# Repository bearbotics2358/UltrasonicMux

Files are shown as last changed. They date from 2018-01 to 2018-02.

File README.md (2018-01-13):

# UltrasonicMux
  This program reads up to 4 Maxbotix ultrasonic sensors and sends
  the output back to the connected computer (CRIO).
  
  The program triggers one sensor at a time and reads its response.
  It waits up to 100 msec for the response.  If none is recevied, it
  substitutes a reading of "999".
  
  A Maxbotix sensor output string example is "R123<CR>".  The program
  substitutes "A", "B", "C", or "D" for the "R", depending on which
  sensor.
  
  The CR is replaced with a TAB for all but the last enabled sensor
  to assist in debugging.
  
  The src/mux subdirectory has the Arduino code for the Ultrasonic Multiplexer.
  
  The src/robot subdirectory has the Sonar class for the robot.

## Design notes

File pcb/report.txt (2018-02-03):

Info: Reading netlist file "V:\Robotics Club\FIRST\Software\17-18 Season\Ultrasonic Mux\pcb\Ultrasonic_mux.net".

Info: Using references to match components and footprints.

Info: Checking netlist component footprint "+3V3p1:/5A757808:Pin_Headers:Pin_Header_Angled_1x01_Pitch2.54mm".

Adding new component "+3V3p1:/5A757808" footprint "Pin_Headers:Pin_Header_Angled_1x01_Pitch2.54mm".

Changing component "+3V3p1:/5A757808" pin "1" net name from "" to "+3V3".

Info: Checking netlist component footprint "+5Vp1:/5A757367:Pin_Headers:Pin_Header_Angled_1x01_Pitch2.54mm".

Adding new component "+5Vp1:/5A757367" footprint "Pin_Headers:Pin_Header_Angled_1x01_Pitch2.54mm".

Changing component "+5Vp1:/5A757367" pin "1" net name from "" to "+5V".

Info: Checking netlist component footprint "D0:/5A6FC6E7:Diodes_SMD:D_SOT-23_ANK".

Adding new component "D0:/5A6FC6E7" footprint "Diodes_SMD:D_SOT-23_ANK".

Changing component "D0:/5A6FC6E7" pin "2" net name from "" to "GNDPWR".

Changing component "D0:/5A6FC6E7" pin "1" net name from "" to "Net-(D0-Pad1)".

Info: Checking netlist component footprint "D1:/5A6FC6FF:LEDs:LED_0805_HandSoldering".

Adding new component "D1:/5A6FC6FF" footprint "LEDs:LED_0805_HandSoldering".

Changing component "D1:/5A6FC6FF" pin "1" net name from "" to "Net-(D1-Pad1)".

Changing component "D1:/5A6FC6FF" pin "2" net name from "" to "+3V3".

Info: Checking netlist component footprint "D2:/5A742F70:LEDs:LED_0603_HandSoldering".

Adding new component "D2:/5A742F70" footprint "LEDs:LED_0603_HandSoldering".

Changing component "D2:/5A742F70" pin "1" net name from "" to "Net-(D2-Pad1)".

Changing component "D2:/5A742F70" pin "2" net name from "" to "+3V3".

Info: Checking netlist component footprint "D10:/5A6FD7F3:Diodes_SMD:D_SOT-23_ANK".

Adding new component "D10:/5A6FD7F3" footprint "Diodes_SMD:D_SOT-23_ANK".

Changing component "D10:/5A6FD7F3" pin "2" net name from "" to "GNDPWR".

Changing component "D10:/5A6FD7F3" pin "1" net name from "" to "Net-(D10-Pad1)".

Info: Checking netlist component footprint "D11:/5A6FD80B:LEDs:LED_0805_HandSoldering".

Adding new component "D11:/5A6FD80B" footprint "LEDs:LED_0805_HandSoldering".

Changing component "D11:/5A6FD80B" pin "1" net name from "" to "Net-(D11-Pad1)".

Changing component "D11:/5A6FD80B" pin "2" net name from "" to "+3V3".

Info: Checking netlist component footprint "D12:/5A73E3A2:LEDs:LED_0603_HandSoldering".

Adding new component "D12:/5A73E3A2" footprint "LEDs:LED_0603_HandSoldering".

Changing component "D12:/5A73E3A2" pin "1" net name from "" to "Net-(D12-Pad1)".

Changing component "D12:/5A73E3A2" pin "2" net name from "" to "+3V3".

Info: Checking netlist component footprint "D20:/5A6FDC3E:Diodes_SMD:D_SOT-23_ANK".

Adding new component "D20:/5A6FDC3E" footprint "Diodes_SMD:D_SOT-23_ANK".

Changing component "D20:/5A6FDC3E" pin "2" net name from "" to "GNDPWR".

Changing component "D20:/5A6FDC3E" pin "1" net name from "" to "Net-(D20-Pad1)".

Info: Checking netlist component footprint "D21:/5A6FDC59:LEDs:LED_0805_HandSoldering".

Adding new component "D21:/5A6FDC59" footprint "LEDs:LED_0805_HandSoldering".

Changing component "D21:/5A6FDC59" pin "1" net name from "" to "Net-(D21-Pad1)".

Changing component "D21:/5A6FDC59" pin "2" net name from "" to "+3V3".

Info: Checking netlist component footprint "D22:/5A74CE13:LEDs:LED_0603_HandSoldering".

Adding new component "D22:/5A74CE13" footprint "LEDs:LED_0603_HandSoldering".

Changing component "D22:/5A74CE13" pin "1" net name from "" to "Net-(D22-Pad1)".

Changing component "D22:/5A74CE13" pin "2" net name from "" to "+3V3".

Info: Checking netlist component footprint "D30:/5A6FF864:Diodes_SMD:D_SOT-23_ANK".

Adding new component "D30:/5A6FF864" footprint "Diodes_SMD:D_SOT-23_ANK".

Changing component "D30:/5A6FF864" pin "2" net name from "" to "GNDPWR".

Changing component "D30:/5A6FF864" pin "1" net name from "" to "Net-(D30-Pad1)".

Info: Checking netlist component footprint "D31:/5A6FF87F:LEDs:LED_0805_HandSoldering".

Adding new component "D31:/5A6FF87F" footprint "LEDs:LED_0805_HandSoldering".

Changing component "D31:/5A6FF87F" pin "1" net name from "" to "Net-(D31-Pad1)".

Changing component "D31:/5A6FF87F" pin "2" net name from "" to "+3V3".

Info: Checking netlist component footprint "D32:/5A74DDF5:LEDs:LED_0603_HandSoldering".

Adding new component "D32:/5A74DDF5" footprint "LEDs:LED_0603_HandSoldering".

Changing component "D32:/5A74DDF5" pin "1" net name from "" to "Net-(D32-Pad1)".

Changing component "D32:/5A74DDF5" pin "2" net name from "" to "+3V3".

Info: Checking netlist component footprint "D40:/5A704642:Diodes_SMD:D_SOT-23_ANK".

Adding new component "D40:/5A704642" footprint "Diodes_SMD:D_SOT-23_ANK".

Changing component "D40:/5A704642" pin "2" net name from "" to "GNDPWR".

Changing component "D40:/5A704642" pin "1" net name from "" to "Net-(D40-Pad1)".

Info: Checking netlist component footprint "D41:/5A70465A:LEDs:LED_0805_HandSoldering".

Adding new component "D41:/5A70465A" footprint "LEDs:LED_0805_HandSoldering".

Changing component "D41:/5A70465A" pin "1" net name from "" to "Net-(D41-Pad1)".

Changing component "D41:/5A70465A" pin "2" net name from "" to "+3V3".

Info: Checking netlist component footprint "D42:/5A753991:LEDs:LED_0603_HandSoldering".

Adding new component "D42:/5A753991" footprint "LEDs:LED_0603_HandSoldering".

Changing component "D42:/5A753991" pin "1" net name from "" to "Net-(D42-Pad1)".

Changing component "D42:/5A753991" pin "2" net name from "" to "+3V3".

Info: Checking netlist component footprint "D50:/5A704680:Diodes_SMD:D_SOT-23_ANK".

Adding new component "D50:/5A704680" footprint "Diodes_SMD:D_SOT-23_ANK".

Changing component "D50:/5A704680" pin "2" net name from "" to "GNDPWR".

Changing component "D50:/5A704680" pin "1" net name from "" to "Net-(D50-Pad1)".

Info: Checking netlist component footprint "D51:/5A704698:LEDs:LED_0805_HandSoldering".

Adding new component "D51:/5A704698" footprint "LEDs:LED_0805_HandSoldering".

Changing component "D51:/5A704698" pin "1" net name from "" to "Net-(D51-Pad1)".

Changing component "D51:/5A704698" pin "2" net name from "" to "+3V3".

Info: Checking netlist component footprint "D52:/5A767ED8:LEDs:LED_0603_HandSoldering".

Adding new component "D52:/5A767ED8" footprint "LEDs:LED_0603_HandSoldering".

Changing component "D52:/5A767ED8" pin "1" net name from "" to "Net-(D52-Pad1)".

Changing component "D52:/5A767ED8" pin "2" net name from "" to "+3V3".

Info: Checking netlist component footprint "GNDp1:/5A757B55:Pin_Headers:Pin_Header_Angled_1x01_Pitch2.54mm".

Adding new component "GNDp1:/5A757B55" footprint "Pin_Headers:Pin_Header_Angled_1x01_Pitch2.54mm".

Changing component "GNDp1:/5A757B55" pin "1" net name from "" to "GNDPWR".

Info: Checking netlist component footprint "J0:/5A6FC6D5:Connectors_DSub:DSUB-9_Male_Vertical_Pitch2.77x2.84mm_MountingHoles".

Adding new component "J0:/5A6FC6D5" footprint "Connectors_DSub:DSUB-9_Male_Vertical_Pitch2.77x2.84mm_MountingHoles".

Changing component "J0:/5A6FC6D5" pin "1" net name from "" to "Net-(J0-Pad1)".

Changing component "J0:/5A6FC6D5" pin "2" net name from "" to "Net-(J0-Pad2)".

Changing component "J0:/5A6FC6D5" pin "3" net name from "" to "Net-(J0-Pad3)".

Changing component "J0:/5A6FC6D5" pin "4" net name from "" to "Net-(J0-Pad4)".

Changing component "J0:/5A6FC6D5" pin "5" net name from "" to "GNDPWR".

Changing component "J0:/5A6FC6D5" pin "6" net name from "" to "Net-(J0-Pad6)".

Changing component "J0:/5A6FC6D5" pin "7" net name from "" to "Net-(J0-Pad7)".

Changing component "J0:/5A6FC6D5" pin "8" net name from "" to "Net-(J0-Pad8)".

Changing component "J0:/5A6FC6D5" pin "9" net name from "" to "Net-(J0-Pad9)".

Info: Checking netlist component footprint "J1:/5A6FD7E1:Connectors_DSub:DSUB-9_Male_Vertical_Pitch2.77x2.84mm_MountingHoles".

Adding new component "J1:/5A6FD7E1" footprint "Connectors_DSub:DSUB-9_Male_Vertical_Pitch2.77x2.84mm_MountingHoles".

Changing component "J1:/5A6FD7E1" pin "1" net name from "" to "Net-(J1-Pad1)".

Changing component "J1:/5A6FD7E1" pin "2" net name from "" to "Net-(J1-Pad2)".

Changing component "J1:/5A6FD7E1" pin "3" net name from "" to "Net-(J1-Pad3)".

Changing component "J1:/5A6FD7E1" pin "4" net name from "" to "Net-(J1-Pad4)".

Changing component "J1:/5A6FD7E1" pin "5" net name from "" to "GNDPWR".

Changing component "J1:/5A6FD7E1" pin "6" net name from "" to "Net-(J1-Pad6)".

Changing component "J1:/5A6FD7E1" pin "7" net name from "" to "Net-(J1-Pad7)".

Changing component "J1:/5A6FD7E1" pin "8" net name from "" to "Net-(J1-Pad8)".

Changing component "J1:/5A6FD7E1" pin "9" net name from "" to "Net-(J1-Pad9)".

Info: Checking netlist component footprint "J2:/5A6FDC29:Connectors_DSub:DSUB-9_Male_Vertical_Pitch2.77x2.84mm_MountingHoles".

Adding new component "J2:/5A6FDC29" footprint "Connectors_DSub:DSUB-9_Male_Vertical_Pitch2.77x2.84mm_MountingHoles".

Changing component "J2:/5A6FDC29" pin "1" net name from "" to "Net-(J2-Pad1)".

Changing component "J2:/5A6FDC29" pin "2" net name from "" to "Net-(J2-Pad2)".

Changing component "J2:/5A6FDC29" pin "3" net name from "" to "Net-(J2-Pad3)".

Changing component "J2:/5A6FDC29" pin "4" net name from "" to "Net-(J2-Pad4)".

Changing component "J2:/5A6FDC29" pin "5" net name from "" to "GNDPWR".

Changing component "J2:/5A6FDC29" pin "6" net name from "" to "Net-(J2-Pad6)".

Changing component "J2:/5A6FDC29" pin "7" net name from "" to "Net-(J2-Pad7)".

Changing component "J2:/5A6FDC29" pin "8" net name from "" to "Net-(J2-Pad8)".

Changing component "J2:/5A6FDC29" pin "9" net name from "" to "Net-(J2-Pad9)".

Info: Checking netlist component footprint "J3:/5A6FF84F:Connectors_DSub:DSUB-9_Male_Vertical_Pitch2.77x2.84mm_MountingHoles".

Adding new component "J3:/5A6FF84F" footprint "Connectors_DSub:DSUB-9_Male_Vertical_Pitch2.77x2.84mm_MountingHoles".

Changing component "J3:/5A6FF84F" pin "1" net name from "" to "Net-(J3-Pad1)".

Changing component "J3:/5A6FF84F" pin "2" net name from "" to "Net-(J3-Pad2)".

Changing component "J3:/5A6FF84F" pin "3" net name from "" to "Net-(J3-Pad3)".

Changing component "J3:/5A6FF84F" pin "4" net name from "" to "Net-(J3-Pad4)".

Changing component "J3:/5A6FF84F" pin "5" net name from "" to "GNDPWR".

Changing component "J3:/5A6FF84F" pin "6" net name from "" to "Net-(J3-Pad6)".

Changing component "J3:/5A6FF84F" pin "7" net name from "" to "Net-(J3-Pad7)".

Changing component "J3:/5A6FF84F" pin "8" net name from "" to "Net-(J3-Pad8)".

Changing component "J3:/5A6FF84F" pin "9" net name from "" to "Net-(J3-Pad9)".

Info: Checking netlist component footprint "J4:/5A704630:Connectors_DSub:DSUB-9_Male_Vertical_Pitch2.77x2.84mm_MountingHoles".

Adding new component "J4:/5A704630" footprint "Connectors_DSub:DSUB-9_Male_Vertical_Pitch2.77x2.84mm_MountingHoles".

Changing component "J4:/5A704630" pin "1" net name from "" to "Net-(J4-Pad1)".

Changing component "J4:/5A704630" pin "2" net name from "" to "Net-(J4-Pad2)".

Changing component "J4:/5A704630" pin "3" net name from "" to "Net-(J4-Pad3)".

Changing component "J4:/5A704630" pin "4" net name from "" to "Net-(J4-Pad4)".

Changing component "J4:/5A704630" pin "5" net name from "" to "GNDPWR".

Changing component "J4:/5A704630" pin "6" net name from "" to "Net-(J4-Pad6)".

Changing component "J4:/5A704630" pin "7" net name from "" to "Net-(J4-Pad7)".

Changing component "J4:/5A704630" pin "8" net name from "" to "Net-(J4-Pad8)".

Changing component "J4:/5A704630" pin "9" net name from "" to "Net-(J4-Pad9)".

Info: Checking netlist component footprint "J5:/5A70466E:Connectors_DSub:DSUB-9_Male_Vertical_Pitch2.77x2.84mm_MountingHoles".

Adding new component "J5:/5A70466E" footprint "Connectors_DSub:DSUB-9_Male_Vertical_Pitch2.77x2.84mm_MountingHoles".

Changing component "J5:/5A70466E" pin "1" net name from "" to "Net-(J5-Pad1)".

Changing component "J5:/5A70466E" pin "2" net name from "" to "Net-(J5-Pad2)".

Changing component "J5:/5A70466E" pin "3" net name from "" to "Net-(J5-Pad3)".

Changing component "J5:/5A70466E" pin "4" net name from "" to "Net-(J5-Pad4)".

Changing component "J5:/5A70466E" pin "5" net name from "" to "GNDPWR".

Changing component "J5:/5A70466E" pin "6" net name from "" to "Net-(J5-Pad6)".

Changing component "J5:/5A70466E" pin "7" net name from "" to "Net-(J5-Pad7)".

Changing component "J5:/5A70466E" pin "8" net name from "" to "Net-(J5-Pad8)".

Changing component "J5:/5A70466E" pin "9" net name from "" to "Net-(J5-Pad9)".

Info: Checking netlist component footprint "J10:/5A725200:Pin_Headers:Pin_Header_Angled_1x03_Pitch2.54mm".

Adding new component "J10:/5A725200" footprint "Pin_Headers:Pin_Header_Angled_1x03_Pitch2.54mm".

Changing component "J10:/5A725200" pin "1" net name from "" to "GNDPWR".

Changing component "J10:/5A725200" pin "2" net name from "" to "+5V".

Changing component "J10:/5A725200" pin "3" net name from "" to "TRG0".

Info: Checking netlist component footprint "J11:/5A72B88E:Pin_Headers:Pin_Header_Angled_1x03_Pitch2.54mm".

Adding new component "J11:/5A72B88E" footprint "Pin_Headers:Pin_Header_Angled_1x03_Pitch2.54mm".

Changing component "J11:/5A72B88E" pin "1" net name from "" to "GNDPWR".

Changing component "J11:/5A72B88E" pin "2" net name from "" to "+5V".

Changing component "J11:/5A72B88E" pin "3" net name from "" to "TRG1".

Info: Checking netlist component footprint "J12:/5A72C619:Pin_Headers:Pin_Header_Angled_1x03_Pitch2.54mm".

Adding new component "J12:/5A72C619" footprint "Pin_Headers:Pin_Header_Angled_1x03_Pitch2.54mm".

Changing component "J12:/5A72C619" pin "1" net name from "" to "GNDPWR".

Changing component "J12:/5A72C619" pin "2" net name from "" to "+5V".

Changing component "J12:/5A72C619" pin "3" net name from "" to "TRG2".

Info: Checking netlist component footprint "J13:/5A72BBAF:Pin_Headers:Pin_Header_Angled_1x03_Pitch2.54mm".

Adding new component "J13:/5A72BBAF" footprint "Pin_Headers:Pin_Header_Angled_1x03_Pitch2.54mm".

Changing component "J13:/5A72BBAF" pin "1" net name from "" to "GNDPWR".

Changing component "J13:/5A72BBAF" pin "2" net name from "" to "+5V".

Changing component "J13:/5A72BBAF" pin "3" net name from "" to "TRG3".

Info: Checking netlist component footprint "J14:/5A730842:Pin_Headers:Pin_Header_Angled_1x03_Pitch2.54mm".

Adding new component "J14:/5A730842" footprint "Pin_Headers:Pin_Header_Angled_1x03_Pitch2.54mm".

Changing component "J14:/5A730842" pin "1" net name from "" to "GNDPWR".

Changing component "J14:/5A730842" pin "2" net name from "" to "+5V".

Changing component "J14:/5A730842" pin "3" net name from "" to "TRG4".

Info: Checking netlist component footprint "J15:/5A740443:Pin_Headers:Pin_Header_Angled_1x03_Pitch2.54mm".

Adding new component "J15:/5A740443" footprint "Pin_Headers:Pin_Header_Angled_1x03_Pitch2.54mm".

Changing component "J15:/5A740443" pin "1" net name from "" to "GNDPWR".

Changing component "J15:/5A740443" pin "2" net name from "" to "+5V".

Changing component "J15:/5A740443" pin "3" net name from "" to "TRG5".

Info: Checking netlist component footprint "P1:/5A751D8A:Pin_Headers:Pin_Header_Angled_1x01_Pitch2.54mm".

Adding new component "P1:/5A751D8A" footprint "Pin_Headers:Pin_Header_Angled_1x01_Pitch2.54mm".

Changing component "P1:/5A751D8A" pin "1" net name from "" to "Net-(P1-Pad1)".

Info: Checking netlist component footprint "P3:/5A752511:Pin_Headers:Pin_Header_Angled_1x01_Pitch2.54mm".

Adding new component "P3:/5A752511" footprint "Pin_Headers:Pin_Header_Angled_1x01_Pitch2.54mm".

Changing component "P3:/5A752511" pin "1" net name from "" to "Net-(P3-Pad1)".

Info: Checking netlist component footprint "P5:/5A75284D:Pin_Headers:Pin_Header_Angled_1x01_Pitch2.54mm".

Adding new component "P5:/5A75284D" footprint "Pin_Headers:Pin_Header_Angled_1x01_Pitch2.54mm".

Changing component "P5:/5A75284D" pin "1" net name from "" to "Net-(P5-Pad1)".

Info: Checking netlist component footprint "P12:/5A752C27:Pin_Headers:Pin_Header_Angled_1x01_Pitch2.54mm".

Adding new component "P12:/5A752C27" footprint "Pin_Headers:Pin_Header_Angled_1x01_Pitch2.54mm".

Changing component "P12:/5A752C27" pin "1" net name from "" to "Net-(P12-Pad1)".

Info: Checking netlist component footprint "P27:/5A7514A6:Pin_Headers:Pin_Header_Angled_1x01_Pitch2.54mm".

Adding new component "P27:/5A7514A6" footprint "Pin_Headers:Pin_Header_Angled_1x01_Pitch2.54mm".

Changing component "P27:/5A7514A6" pin "1" net name from "" to "Net-(P27-Pad1)".

Info: Checking netlist component footprint "P28:/5A7515EB:Pin_Headers:Pin_Header_Angled_1x01_Pitch2.54mm".

Adding new component "P28:/5A7515EB" footprint "Pin_Headers:Pin_Header_Angled_1x01_Pitch2.54mm".

Changing component "P28:/5A7515EB" pin "1" net name from "" to "Net-(P28-Pad1)".

Info: Checking netlist component footprint "Q0:/5A6FC6DB:TO_SOT_Packages_SMD:SOT-23".

Adding new component "Q0:/5A6FC6DB" footprint "TO_SOT_Packages_SMD:SOT-23".

Changing component "Q0:/5A6FC6DB" pin "1" net name from "" to "Net-(D0-Pad1)".

Changing component "Q0:/5A6FC6DB" pin "2" net name from "" to "GNDPWR".

Changing component "Q0:/5A6FC6DB" pin "3" net name from "" to "RX0".

Info: Checking netlist component footprint "Q1:/5A6FD7E7:TO_SOT_Packages_SMD:SOT-23".

Adding new component "Q1:/5A6FD7E7" footprint "TO_SOT_Packages_SMD:SOT-23".

Changing component "Q1:/5A6FD7E7" pin "1" net name from "" to "Net-(D10-Pad1)".

Changing component "Q1:/5A6FD7E7" pin "2" net name from "" to "GNDPWR".

Changing component "Q1:/5A6FD7E7" pin "3" net name from "" to "RX1".

Info: Checking netlist component footprint "Q2:/5A6FDC30:TO_SOT_Packages_SMD:SOT-23".

Adding new component "Q2:/5A6FDC30" footprint "TO_SOT_Packages_SMD:SOT-23".

Changing component "Q2:/5A6FDC30" pin "1" net name from "" to "Net-(D20-Pad1)".

Changing component "Q2:/5A6FDC30" pin "2" net name from "" to "GNDPWR".

Changing component "Q2:/5A6FDC30" pin "3" net name from "" to "RX2".

Info: Checking netlist component footprint "Q3:/5A6FF856:TO_SOT_Packages_SMD:SOT-23".

Adding new component "Q3:/5A6FF856" footprint "TO_SOT_Packages_SMD:SOT-23".

Changing component "Q3:/5A6FF856" pin "1" net name from "" to "Net-(D30-Pad1)".

Changing component "Q3:/5A6FF856" pin "2" net name from "" to "GNDPWR".

Changing component "Q3:/5A6FF856" pin "3" net name from "" to "RX3".

Info: Checking netlist component footprint "Q4:/5A704636:TO_SOT_Packages_SMD:SOT-23".

Adding new component "Q4:/5A704636" footprint "TO_SOT_Packages_SMD:SOT-23".

Changing component "Q4:/5A704636" pin "1" net name from "" to "Net-(D40-Pad1)".

Changing component "Q4:/5A704636" pin "2" net name from "" to "GNDPWR".

Changing component "Q4:/5A704636" pin "3" net name from "" to "RX4".

Info: Checking netlist component footprint "Q5:/5A704674:TO_SOT_Packages_SMD:SOT-23".

Adding new component "Q5:/5A704674" footprint "TO_SOT_Packages_SMD:SOT-23".

Changing component "Q5:/5A704674" pin "1" net name from "" to "Net-(D50-Pad1)".

Changing component "Q5:/5A704674" pin "2" net name from "" to "GNDPWR".

Changing component "Q5:/5A704674" pin "3" net name from "" to "RX5".

Info: Checking netlist component footprint "R0:/5A6FC6ED:Resistors_SMD:R_0805_HandSoldering".

Adding new component "R0:/5A6FC6ED" footprint "Resistors_SMD:R_0805_HandSoldering".

Changing component "R0:/5A6FC6ED" pin "1" net name from "" to "Net-(J0-Pad2)".

Changing component "R0:/5A6FC6ED" pin "2" net name from "" to "Net-(D0-Pad1)".

Info: Checking netlist component footprint "R1:/5A6FC6E1:Resistors_SMD:R_0805_HandSoldering".

Adding new component "R1:/5A6FC6E1" footprint "Resistors_SMD:R_0805_HandSoldering".

Changing component "R1:/5A6FC6E1" pin "1" net name from "" to "GNDPWR".

Changing component "R1:/5A6FC6E1" pin "2" net name from "" to "Net-(D0-Pad1)".

Info: Checking netlist component footprint "R2:/5A6FC6F3:Resistors_SMD:R_0805_HandSoldering".

Adding new component "R2:/5A6FC6F3" footprint "Resistors_SMD:R_0805_HandSoldering".

Changing component "R2:/5A6FC6F3" pin "1" net name from "" to "RX0".

Changing component "R2:/5A6FC6F3" pin "2" net name from "" to "Net-(D1-Pad1)".

Info: Checking netlist component footprint "R3:/5A742F7D:Resistors_SMD:R_0805_HandSoldering".

Adding new component "R3:/5A742F7D" footprint "Resistors_SMD:R_0805_HandSoldering".

Changing component "R3:/5A742F7D" pin "1" net name from "" to "IND0".

Changing component "R3:/5A742F7D" pin "2" net name from "" to "Net-(D2-Pad1)".

Info: Checking netlist component footprint "R10:/5A6FD7F9:Resistors_SMD:R_0805_HandSoldering".

Adding new component "R10:/5A6FD7F9" footprint "Resistors_SMD:R_0805_HandSoldering".

Changing component "R10:/5A6FD7F9" pin "1" net name from "" to "Net-(J1-Pad2)".

Changing component "R10:/5A6FD7F9" pin "2" net name from "" to "Net-(D10-Pad1)".

Info: Checking netlist component footprint "R11:/5A6FD7ED:Resistors_SMD:R_0805_HandSoldering".

Adding new component "R11:/5A6FD7ED" footprint "Resistors_SMD:R_0805_HandSoldering".

Changing component "R11:/5A6FD7ED" pin "1" net name from "" to "GNDPWR".

Changing component "R11:/5A6FD7ED" pin "2" net name from "" to "Net-(D10-Pad1)".

Info: Checking netlist component footprint "R12:/5A6FD7FF:Resistors_SMD:R_0805_HandSoldering".

Adding new component "R12:/5A6FD7FF" footprint "Resistors_SMD:R_0805_HandSoldering".

Changing component "R12:/5A6FD7FF" pin "1" net name from "" to "RX1".

Changing component "R12:/5A6FD7FF" pin "2" net name from "" to "Net-(D11-Pad1)".

Info: Checking netlist component footprint "R13:/5A73E3AF:Resistors_SMD:R_0805_HandSoldering".

Adding new component "R13:/5A73E3AF" footprint "Resistors_SMD:R_0805_HandSoldering".

Changing component "R13:/5A73E3AF" pin "1" net name from "" to "IND1".

Changing component "R13:/5A73E3AF" pin "2" net name from "" to "Net-(D12-Pad1)".

Info: Checking netlist component footprint "R20:/5A6FDC45:Resistors_SMD:R_0805_HandSoldering".

Adding new component "R20:/5A6FDC45" footprint "Resistors_SMD:R_0805_HandSoldering".

Changing component "R20:/5A6FDC45" pin "1" net name from "" to "Net-(J2-Pad2)".

Changing component "R20:/5A6FDC45" pin "2" net name from "" to "Net-(D20-Pad1)".

Info: Checking netlist component footprint "R21:/5A6FDC37:Resistors_SMD:R_0805_HandSoldering".

Adding new component "R21:/5A6FDC37" footprint "Resistors_SMD:R_0805_HandSoldering".

Changing component "R21:/5A6FDC37" pin "1" net name from "" to "GNDPWR".

Changing component "R21:/5A6FDC37" pin "2" net name from "" to "Net-(D20-Pad1)".

Info: Checking netlist component footprint "R22:/5A6FDC4C:Resistors_SMD:R_0805_HandSoldering".

Adding new component "R22:/5A6FDC4C" footprint "Resistors_SMD:R_0805_HandSoldering".

Changing component "R22:/5A6FDC4C" pin "1" net name from "" to "RX2".

Changing component "R22:/5A6FDC4C" pin "2" net name from "" to "Net-(D21-Pad1)".

Info: Checking netlist component footprint "R23:/5A74CE20:Resistors_SMD:R_0805_HandSoldering".

Adding new component "R23:/5A74CE20" footprint "Resistors_SMD:R_0805_HandSoldering".

Changing component "R23:/5A74CE20" pin "1" net name from "" to "IND2".

Changing component "R23:/5A74CE20" pin "2" net name from "" to "Net-(D22-Pad1)".

Info: Checking netlist component footprint "R30:/5A6FF86B:Resistors_SMD:R_0805_HandSoldering".

Adding new component "R30:/5A6FF86B" footprint "Resistors_SMD:R_0805_HandSoldering".

Changing component "R30:/5A6FF86B" pin "1" net name from "" to "Net-(J3-Pad2)".

Changing component "R30:/5A6FF86B" pin "2" net name from "" to "Net-(D30-Pad1)".

Info: Checking netlist component footprint "R31:/5A6FF85D:Resistors_SMD:R_0805_HandSoldering".

Adding new component "R31:/5A6FF85D" footprint "Resistors_SMD:R_0805_HandSoldering".

Changing component "R31:/5A6FF85D" pin "1" net name from "" to "GNDPWR".

Changing component "R31:/5A6FF85D" pin "2" net name from "" to "Net-(D30-Pad1)".

Info: Checking netlist component footprint "R32:/5A6FF872:Resistors_SMD:R_0805_HandSoldering".

Adding new component "R32:/5A6FF872" footprint "Resistors_SMD:R_0805_HandSoldering".

Changing component "R32:/5A6FF872" pin "1" net name from "" to "RX3".

Changing component "R32:/5A6FF872" pin "2" net name from "" to "Net-(D31-Pad1)".

Info: Checking netlist component footprint "R33:/5A74DE02:Resistors_SMD:R_0805_HandSoldering".

Adding new component "R33:/5A74DE02" footprint "Resistors_SMD:R_0805_HandSoldering".

Changing component "R33:/5A74DE02" pin "1" net name from "" to "IND3".

Changing component "R33:/5A74DE02" pin "2" net name from "" to "Net-(D32-Pad1)".

Info: Checking netlist component footprint "R40:/5A704648:Resistors_SMD:R_0805_HandSoldering".

Adding new component "R40:/5A704648" footprint "Resistors_SMD:R_0805_HandSoldering".

Changing component "R40:/5A704648" pin "1" net name from "" to "Net-(J4-Pad2)".

Changing component "R40:/5A704648" pin "2" net name from "" to "Net-(D40-Pad1)".

Info: Checking netlist component footprint "R41:/5A70463C:Resistors_SMD:R_0805_HandSoldering".

Adding new component "R41:/5A70463C" footprint "Resistors_SMD:R_0805_HandSoldering".

Changing component "R41:/5A70463C" pin "1" net name from "" to "GNDPWR".

Changing component "R41:/5A70463C" pin "2" net name from "" to "Net-(D40-Pad1)".

Info: Checking netlist component footprint "R42:/5A70464E:Resistors_SMD:R_0805_HandSoldering".

Adding new component "R42:/5A70464E" footprint "Resistors_SMD:R_0805_HandSoldering".

Changing component "R42:/5A70464E" pin "1" net name from "" to "RX4".

Changing component "R42:/5A70464E" pin "2" net name from "" to "Net-(D41-Pad1)".

Info: Checking netlist component footprint "R43:/5A75399E:Resistors_SMD:R_0805_HandSoldering".

Adding new component "R43:/5A75399E" footprint "Resistors_SMD:R_0805_HandSoldering".

Changing component "R43:/5A75399E" pin "1" net name from "" to "IND4".

Changing component "R43:/5A75399E" pin "2" net name from "" to "Net-(D42-Pad1)".

Info: Checking netlist component footprint "R50:/5A704686:Resistors_SMD:R_0805_HandSoldering".

Adding new component "R50:/5A704686" footprint "Resistors_SMD:R_0805_HandSoldering".

Changing component "R50:/5A704686" pin "1" net name from "" to "Net-(J5-Pad2)".

Changing component "R50:/5A704686" pin "2" net name from "" to "Net-(D50-Pad1)".

Info: Checking netlist component footprint "R51:/5A70467A:Resistors_SMD:R_0805_HandSoldering".

Adding new component "R51:/5A70467A" footprint "Resistors_SMD:R_0805_HandSoldering".

Changing component "R51:/5A70467A" pin "1" net name from "" to "GNDPWR".

Changing component "R51:/5A70467A" pin "2" net name from "" to "Net-(D50-Pad1)".

Info: Checking netlist component footprint "R52:/5A70468C:Resistors_SMD:R_0805_HandSoldering".

Adding new component "R52:/5A70468C" footprint "Resistors_SMD:R_0805_HandSoldering".

Changing component "R52:/5A70468C" pin "1" net name from "" to "RX5".

Changing component "R52:/5A70468C" pin "2" net name from "" to "Net-(D51-Pad1)".

Info: Checking netlist component footprint "R53:/5A767EE5:Resistors_SMD:R_0805_HandSoldering".

Adding new component "R53:/5A767EE5" footprint "Resistors_SMD:R_0805_HandSoldering".

Changing component "R53:/5A767EE5" pin "1" net name from "" to "IND5".

Changing component "R53:/5A767EE5" pin "2" net name from "" to "Net-(D52-Pad1)".

Info: Checking netlist component footprint "U1:/5A6FB328:Feather M0:featherm0".

Adding new component "U1:/5A6FB328" footprint "Feather M0:featherm0".

Changing component "U1:/5A6FB328" pin "1" net name from "" to "Net-(P1-Pad1)".

Changing component "U1:/5A6FB328" pin "2" net name from "" to "+3V3".

Changing component "U1:/5A6FB328" pin "3" net name from "" to "Net-(P3-Pad1)".

Changing component "U1:/5A6FB328" pin "4" net name from "" to "GNDPWR".

Changing component "U1:/5A6FB328" pin "28" net name from "" to "Net-(P28-Pad1)".

Changing component "U1:/5A6FB328" pin "5" net name from "" to "Net-(P5-Pad1)".

Changing component "U1:/5A6FB328" pin "27" net name from "" to "Net-(P27-Pad1)".

Changing component "U1:/5A6FB328" pin "6" net name from "" to "RX4".

Changing component "U1:/5A6FB328" pin "26" net name from "" to "+5V".

Changing component "U1:/5A6FB328" pin "7" net name from "" to "TRG4".

Changing component "U1:/5A6FB328" pin "25" net name from "" to "TRG1".

Changing component "U1:/5A6FB328" pin "8" net name from "" to "RX0".

Changing component "U1:/5A6FB328" pin "24" net name from "" to "IND1".

Changing component "U1:/5A6FB328" pin "9" net name from "" to "TRG0".

Changing component "U1:/5A6FB328" pin "23" net name from "" to "RX1".

Changing component "U1:/5A6FB328" pin "10" net name from "" to "IND5".

Changing component "U1:/5A6FB328" pin "22" net name from "" to "RX3".

Changing component "U1:/5A6FB328" pin "11" net name from "" to "IND4".

Changing component "U1:/5A6FB328" pin "21" net name from "" to "IND0".

Changing component "U1:/5A6FB328" pin "12" net name from "" to "Net-(P12-Pad1)".

Changing component "U1:/5A6FB328" pin "20" net name from "" to "TRG3".

Changing component "U1:/5A6FB328" pin "13" net name from "" to "RX2".

Changing component "U1:/5A6FB328" pin "19" net name from "" to "IND3".

Changing component "U1:/5A6FB328" pin "14" net name from "" to "IND2".

Changing component "U1:/5A6FB328" pin "18" net name from "" to "TRG5".

Changing component "U1:/5A6FB328" pin "15" net name from "" to "TRG2".

Changing component "U1:/5A6FB328" pin "17" net name from "" to "RX5".

Changing component "U1:/5A6FB328" pin "16" net name from "" to "GNDPWR".

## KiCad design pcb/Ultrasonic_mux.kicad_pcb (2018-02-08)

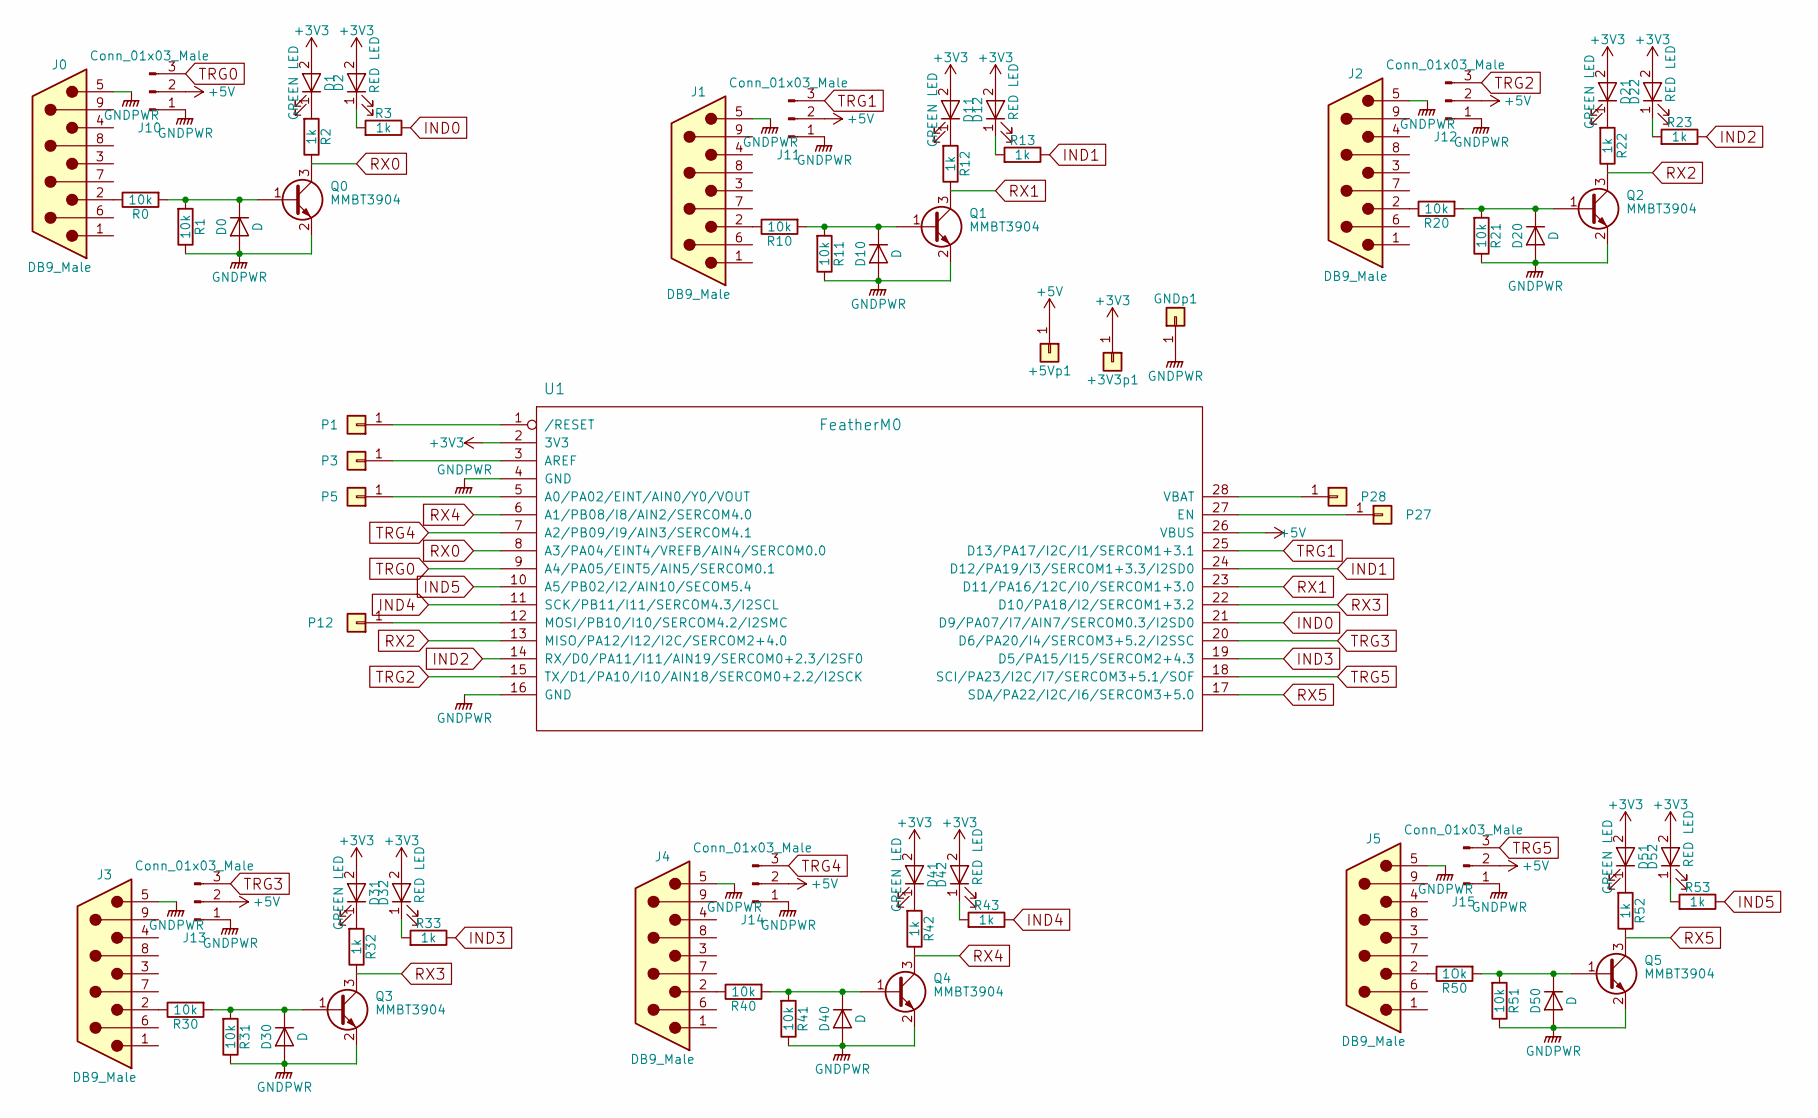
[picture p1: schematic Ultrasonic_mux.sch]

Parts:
+3V3p1, +5Vp1: Pin_Header_Straight_1x01_Pitch2.54mm
D0, D10, D20, D30, D40, D50: D; D_SOT-23_ANK
D1, D11, D21, D31, D41, D51: GREEN LED; LED_0805_HandSoldering
D2, D12, D22, D32, D42, D52: RED LED; LED_0603_HandSoldering
GNDp1: Pin_Header_Straight_1x01_Pitch2.54mm
J0, J1, J2, J3, J4, J5: DB9_Male; DSUB-9_Male_Vertical_Pitch2.77x2.84mm_MountingHoles
J10, J11, J12, J13, J14, J15: Conn_01x03_Male; Pin_Header_Straight_1x03_Pitch2.54mm
P1, P3, P5, P12, P27, P28: Pin_Header_Straight_1x01_Pitch2.54mm
Q0, Q1, Q2, Q3, Q4, Q5: MMBT3904; SOT-23
R0, R1, R10, R11, R20, R21, R30, R31, R40, R41, R51: 10k; R_0805_HandSoldering
R2, R3, R12, R13, R22, R23, R32, R33, R42, R43, R52, R53: 1k; R_0805_HandSoldering
R50: 1Ok; R_0805_HandSoldering
U1: FeatherM0; featherm0

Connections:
+3V3: +3V3p1.1, D1.2 (A), D2.2 (A), D11.2 (A), D12.2 (A), D21.2 (A), D22.2 (A), D31.2 (A), D32.2 (A), D41.2 (A), D42.2 (A), D51.2 (A), D52.2 (A), U1.2 (3V3)
+5V: +5Vp1.1, J10.2, J11.2, J12.2, J13.2, J14.2, J15.2, U1.26 (VBUS)
GNDPWR: D0.2 (A), D10.2 (A), D20.2 (A), D30.2 (A), D40.2 (A), D50.2 (A), GNDp1.1, J0.5, J1.5, J2.5, J3.5, J4.5, J5.5, J10.1, J11.1, J12.1, J13.1, J14.1, J15.1, Q0.2 (E), Q1.2 (E), Q2.2 (E), Q3.2 (E), Q4.2 (E), Q5.2 (E), R1.1, R11.1, R21.1, R31.1, R41.1, R51.1, U1.4 (GND), U1.16 (GND)
IND0: R3.1, U1.21 (D9/PA07/I7/AIN7/SERCOM0.3/I2SD0)
IND1: R13.1, U1.24 (D12/PA19/I3/SERCOM1+3.3/I2SD0)
IND2: R23.1, U1.14 (RX/D0/PA11/I11/AIN19/SERCOM0+2.3/I2SF0)
IND3: R33.1, U1.19 (D5/PA15/I15/SERCOM2+4.3)
IND4: R43.1, U1.11 (SCK/PB11/I11/SERCOM4.3/I2SCL)
IND5: R53.1, U1.10 (A5/PB02/I2/AIN10/SECOM5.4)
unnamed: D0.1 (K), Q0.1 (B), R0.2, R1.2
unnamed: D1.1 (K), R2.2
unnamed: D2.1 (K), R3.2
unnamed: D10.1 (K), Q1.1 (B), R10.2, R11.2
unnamed: D11.1 (K), R12.2
unnamed: D12.1 (K), R13.2
unnamed: D20.1 (K), Q2.1 (B), R20.2, R21.2
unnamed: D21.1 (K), R22.2
unnamed: D22.1 (K), R23.2
unnamed: D30.1 (K), Q3.1 (B), R30.2, R31.2
unnamed: D31.1 (K), R32.2
unnamed: D32.1 (K), R33.2
unnamed: D40.1 (K), Q4.1 (B), R40.2, R41.2
unnamed: D41.1 (K), R42.2
unnamed: D42.1 (K), R43.2
unnamed: D50.1 (K), Q5.1 (B), R50.2, R51.2
unnamed: D51.1 (K), R52.2
unnamed: D52.1 (K), R53.2
unnamed: J0.2, R0.1
unnamed: J1.2, R10.1
unnamed: J2.2, R20.1
unnamed: J3.2, R30.1
unnamed: J4.2, R40.1
unnamed: J5.2, R50.1
unnamed: P1.1, U1.1 (/RESET)
unnamed: P3.1, U1.3 (AREF)
unnamed: P5.1, U1.5 (A0/PA02/EINT/AIN0/Y0/VOUT)
unnamed: P12.1, U1.12 (MOSI/PB10/I10/SERCOM4.2/I2SMC)
unnamed: P27.1, U1.27 (EN)
unnamed: P28.1, U1.28 (VBAT)
RX0: Q0.3 (C), R2.1, U1.8 (A3/PA04/EINT4/VREFB/AIN4/SERCOM0.0)
RX1: Q1.3 (C), R12.1, U1.23 (D11/PA16/12C/I0/SERCOM1+3.0)
RX2: Q2.3 (C), R22.1, U1.13 (MISO/PA12/I12/I2C/SERCOM2+4.0)
RX3: Q3.3 (C), R32.1, U1.22 (D10/PA18/I2/SERCOM1+3.2)
RX4: Q4.3 (C), R42.1, U1.6 (A1/PB08/I8/AIN2/SERCOM4.0)
RX5: Q5.3 (C), R52.1, U1.17 (SDA/PA22/I2C/I6/SERCOM3+5.0)
TRG0: J10.3, U1.9 (A4/PA05/EINT5/AIN5/SERCOM0.1)
TRG1: J11.3, U1.25 (D13/PA17/I2C/I1/SERCOM1+3.1)
TRG2: J12.3, U1.15 (TX/D1/PA10/I10/AIN18/SERCOM0+2.2/I2SCK)
TRG3: J13.3, U1.20 (D6/PA20/I4/SERCOM3+5.2/I2SSC)
TRG4: J14.3, U1.7 (A2/PB09/I9/AIN3/SERCOM4.1)
TRG5: J15.3, U1.18 (SCI/PA23/I2C/I7/SERCOM3+5.1/SOF)

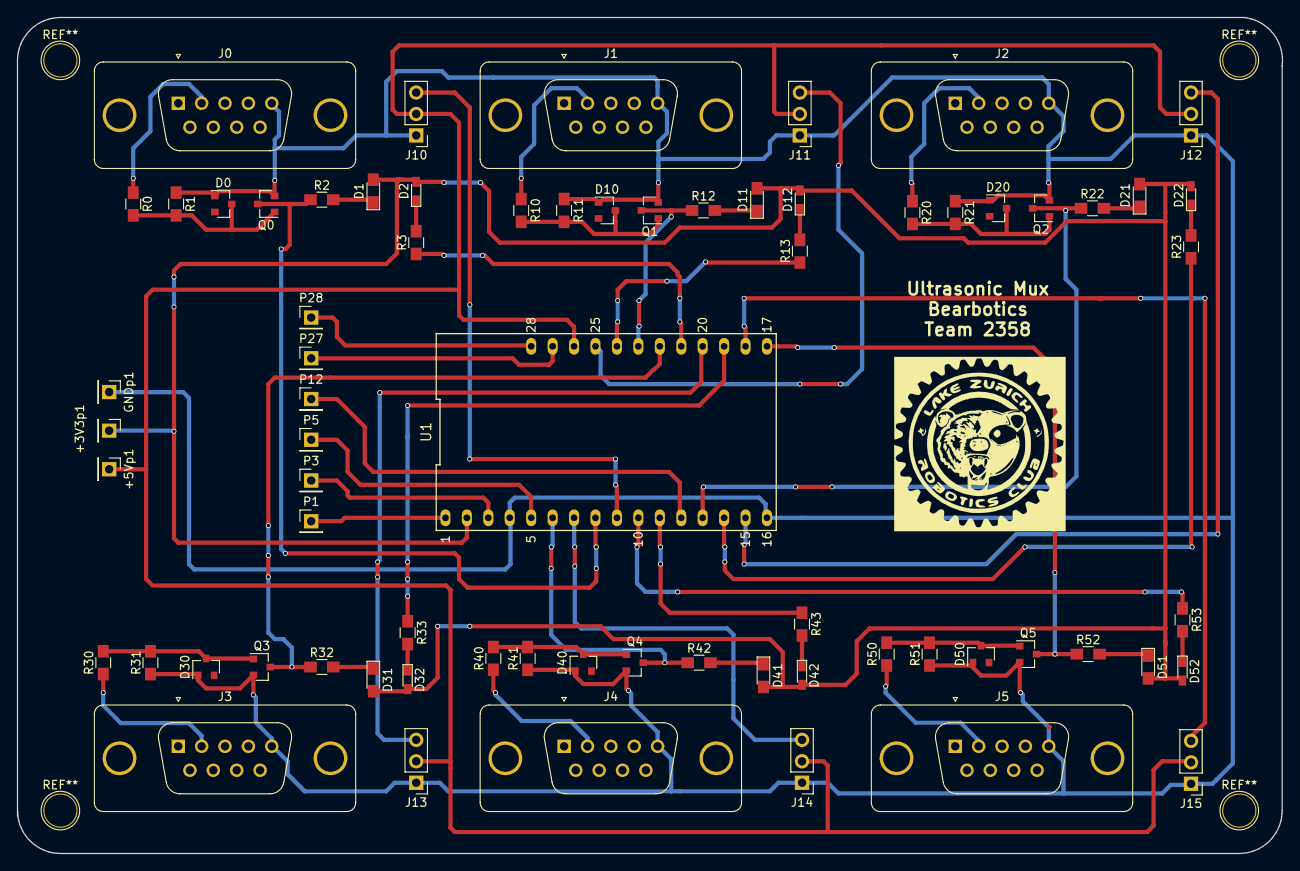
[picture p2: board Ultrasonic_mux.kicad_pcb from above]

Board: 2 copper layers, 149.9 x 99.1 mm, 70 parts (0 on the bottom side), 51 nets.

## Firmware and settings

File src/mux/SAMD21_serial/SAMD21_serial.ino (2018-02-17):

/*
  AnalogReadSerial on ne UART placed on pins 0 and 1
  Reads an analog input on pin A0, prints the result to the serial monitor.
  Graphical representation is available using serial plotter (Tools > Serial Plotter menu)
  Attach the center pin of a potentiometer to pin A0, and the outside pins to +3.3V and ground.
  Short together pin 0 and pin 1 with a wire jumper

 Created 20 Jun 2016
 by
 Arturo Guadalupi <a.guadalupi@arduino.cc>

  This example code is in the public domain.

  Note:
  Commented out SERCOM0 stuff at end of:

  /home/bobd/.arduino15/packages/adafruit/hardware/samd/1.0.22/variants/feather_m0/variant.cpp:218: multiple definition of `SERCOM0_Handler'
sketch/SAMD21_serial.ino.cpp.o:/home/bobd/Arduino/sketches/SAMD21_serial/SAMD21_serial.ino:69: first defined here


  updated 2/16/18
  - working: sercoms 0, 1, 2, 3, 4, 5


*/

#include <Arduino.h>
#include "wiring_private.h"

Uart mySerial0 (&sercom0, A3, -1, SERCOM_RX_PAD_0, UART_TX_PAD_2); // Create the new UART instance
Uart mySerial1 (&sercom1, 11, -1, SERCOM_RX_PAD_0, UART_TX_PAD_2); // Create the new UART instance
Uart mySerial2 (&sercom2, PIN_SPI_MISO, -1, SERCOM_RX_PAD_0, UART_TX_PAD_2); // Create the new UART instance
Uart mySerial3 (&sercom3, 10, -1, SERCOM_RX_PAD_2, UART_TX_PAD_0); // Create the new UART instance
Uart mySerial4 (&sercom4, A1, -1, SERCOM_RX_PAD_0, UART_TX_PAD_2); // Create the new UART instance
Uart mySerial5 (&sercom5, SDA, -1, SERCOM_RX_PAD_0, UART_TX_PAD_2); // Create the new UART instance

Uart *mySerials[] = {&mySerial0, &mySerial1, &mySerial2, &mySerial3, &mySerial4, &mySerial5};
// trigger pins
int trigs[] = {A4, 13, 1, 6, A2, 21}; // is 21 legal?
int msg_rcvd[6];

#define IND0 9

int led0 = 0;

char buf[6][80];
int nbuf[6];
long t1;

void setup() {
  int i;
  
  // initialize serial communication at 9600 bits per second:
  Serial.begin(115200);

  mySerial0.begin(9600);
  mySerial1.begin(9600);
  mySerial2.begin(9600);
  mySerial3.begin(9600);
  mySerial4.begin(9600);
  mySerial5.begin(9600);

  pinPeripheral(A3, PIO_SERCOM_ALT); // sercom0 - Assign RX function to pin
  pinPeripheral(11, PIO_SERCOM); // sercom1 - Assign RX function to pin
  pinPeripheral(PIN_SPI_MISO, PIO_SERCOM); // sercom2 - Assign RX function to pin
  pinPeripheral(10, PIO_SERCOM_ALT); // sercom3 - Assign RX function to pin
  pinPeripheral(A1, PIO_SERCOM_ALT); // sercom4 - Assign RX function to pin
  pinPeripheral(SDA, PIO_SERCOM_ALT); // sercom5 - Assign RX function to pin

  pinMode(13, OUTPUT);
  pinMode(IND0, OUTPUT);

  digitalWrite(13, HIGH);   // turn the LED on (HIGH is the voltage level)
  digitalWrite(IND0, HIGH);
  delay(1000);              // wait for a second
  digitalWrite(13, LOW);    // turn the LED off by making the voltage LOW
  digitalWrite(IND0, LOW);
  led0 = 0;
  delay(1000);              // wait for a second


  Serial.println("@4 It's alive 2!");
  delay(1000);

  for(i = 0; i < 6; i++) {
    nbuf[i] = 0;
    msg_rcvd[i] = 0;
  }

  for(i = 0; i < 6; i++) {
    pinMode(trigs[i], OUTPUT);
  }
  
  trigger_all(HIGH);
  t1 = millis();
}

void trigger_all(int onoff) {
  int i;
  
  // turn all triggers on or off
  for(i = 0; i < 6; i++) {
    trigger(i, onoff);
  }  
}

void trigger(int chan, int onoff) {
  int i;
  
  // For the Ultrasonics, on is high
  // for the Ultrasonic Mux, it is buffered thru an inverter
  if(onoff) {
    // inverted logic
    digitalWrite(trigs[i], 0);
  } else {
    digitalWrite(trigs[i], 1);
  }
}

int all_msgs_rcvd() {
  int ret = 1;
  int i;

  for(i = 0; i < 6; i++) {
    if(!msg_rcvd[i]) {
      ret = 0;
      break;
    }
  }
  return ret;
}

int clear_msgs_rcvd() {
  int i;

  for(i = 0; i < 6; i++) {
    msg_rcvd[i] = 0;
  }
}


void loop() {
  char c;
  int i;

  if(millis() > t1 + 100) {
    // stop waiting
    for(i = 0; i < 6; i++) {
      if(!msg_rcvd[i]) {
        // put in bogus reading
        buf[i][0] = 'A' + i;
        buf[i][1] = '9';
        buf[i][2] = '9';
        buf[i][3] = '9';
        buf[i][4] = '9';
        buf[i][5] = 0;
        msg_rcvd[i] = 1;
      }
    }
  }
  
  if(all_msgs_rcvd()) {
    clear_msgs_rcvd();
    for(int j = 0; j < 6; j++) {
      Serial.print(buf[j]);
      if(j == 5) {
        Serial.print('\r');
      } else {
        Serial.print('\t');
      }
    }
    
    // For now, trigger all at the same time
    trigger_all(1);
    t1 = millis();    
  }
  
  for(i = 0; i < 6; i++) {
    while(mySerials[i]->available()) {
     c = mySerials[i]->read();
     // Serial.print("0x");
     // Serial.println(c, HEX);
     buf[i][nbuf[i]] = c;
     if(nbuf[i] == 0) {
       // replace 'R' with channel letter
       buf[i][0] = 'A' + i; 
     }
     if(c == '\r') {
       buf[i][nbuf[i]] = 0;
       // Serial.print(i);
       // Serial.print(": ");
       // Serial.println(buf[i]);
       nbuf[i] = 0;
       led0 = !led0;
       digitalWrite(IND0, led0);
       // turn off trigger to this channel
       trigger(i, 0);
       msg_rcvd[i] = 1;
     } else {
      nbuf[i]++;
      if(nbuf[i] > 79) {
        nbuf[i] = 0;
      }
     }
   }

   delay(1);        // delay in between reads for stability
  }
}

// Attach the interrupt handler to the SERCOM
void SERCOM0_Handler()
{
  mySerial0.IrqHandler();
}

// Attach the interrupt handler to the SERCOM
void SERCOM1_Handler()
{
  mySerial1.IrqHandler();
}

// Attach the interrupt handler to the SERCOM
void SERCOM2_Handler()
{
  mySerial2.IrqHandler();
}

// Attach the interrupt handler to the SERCOM
void SERCOM3_Handler()
{
  mySerial3.IrqHandler();
}

// Attach the interrupt handler to the SERCOM
void SERCOM4_Handler()
{
  mySerial4.IrqHandler();
}

// Attach the interrupt handler to the SERCOM
void SERCOM5_Handler()
{
  mySerial5.IrqHandler();
}

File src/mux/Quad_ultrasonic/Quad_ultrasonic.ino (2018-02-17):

/*
  Quad_ultrasonic
  
  This program reads up to 4 Maxbotix ultrasonic sensors and sends
  the output back to the connected computer (CRIO).
  
  The program triggers one sensor at a time and reads its response.
  It waits up to 100 msec for the response.  If none recevied, it
  substitutes a reading of "999".
  
  A Maxbotix sensor output string example is "R123<CR>".  The program
  substitutes "A", "B", "C", or "D" for the "R", depending on which
  sensor.
  
  The CR is replaced with a TAB for all but the last enabled sensor
  to assist in debugging.
  
  The program uses the Software Serial to read the sensors.  This
  must be the New Software Serial library.  It is the included lib
  for version of Arduino >= 1...
  
  Not all pins on the Leonardo support change interrupts, 
 so only the following can be used for RX: 
 8, 9, 10, 11, 14 (MISO), 15 (SCK), 16 (MOSI).
 
 created 2/12/14 BD from a dual software serial example
 
 updated 2/15/14
 - adding commands to this unit from CRIO
 A0, A1, B0, B1, C0, C1, D0, D1
 updated 2/16/14
 - all working now
 
 
 */

#include <SoftwareSerial.h>
#include <ctype.h>

SoftwareSerial *serial[4];

// trigger lines to sensors
int trig[4] = {8, 7, 6, 5};
// indicate which channel is currently active
int leds[4] = {10, 15, 17, 19};
// channel tx letters
int letters[4] = {'A', 'B', 'C', 'D'};
// channel enable flags
int enable[4] = {1, 1, 1, 1};
// flag for simultaneous operation
int simul = 0;
char cmd_buf[10];
int cmd_index = 0;

int i;
long t1;

void setup()
{
  // port to CRIO
  Serial.begin(38400);

  // SoftwareSerial(rx pin,tx pin, inverted)
  serial[0] = new SoftwareSerial(9, 2, false);
  serial[1] = new SoftwareSerial(14, 2, false);
  serial[2] = new SoftwareSerial(16, 2, false);
  serial[3] = new SoftwareSerial(18, 2, false);

  for(i = 0; i < 4; i++) {
    // Start each software serial port
    serial[i]->begin(9600);
    // Setup trigger outputs
    pinMode(trig[i], OUTPUT);
    digitalWrite(trig[i], LOW);
    // Setup indicator leds
    pinMode(leds[i], OUTPUT);
    digitalWrite(leds[i], LOW);
  }
}

void loop()
{
  char rxbuf[10];
  int j;
  int max_sensor = 0;
  char c1;
  char c2;
  int k;

  // get command if there is one
  // every time through loop, get command chars if available
  // when '\r' (or '\n') found, process command
  while(Serial.available() > 0) {
    cmd_buf[cmd_index] = Serial.read();
    if((cmd_buf[cmd_index] == '\r') 
      || (cmd_buf[cmd_index] == '\n')) {
      // process command
      cmd_buf[cmd_index + 1] = 0;
      //Serial.print("cmd = ");
      Serial.println(cmd_buf);
      if(cmd_index == 2) {
        // temp variables in case optimizer is not efficient
        c1 = toupper(cmd_buf[0]);
        c2 = cmd_buf[1];
        if((c1 >= 'A') && (c1 <= 'D')) {
          if((c2 >= '0') && (c2 <= '1')) {
            enable[int(c1 - 'A')] = int(c2 - '0');
          }
        } else if(c1 == 'S') {
           if((c2 >= '0') && (c2 <= '1')) {
            simul = int(c2 - '0');
          }
        }
      }

      // reset for next command
      cmd_index = 0;
    } else {
      cmd_index++;
    }
  }
  
  // check and process sensors
  for(i = 0; i < 4; i++) {
    // clear receive buffer
    for(j = 0; j < 10; j++) {
      rxbuf[j] = 0;
    }
    if(enable[i]) {
      // if this channel enabled, trigger and read it
      // indicate active channel
      digitalWrite(leds[i], HIGH);
      // activate serial port and clear rx buff
      serial[i]->listen();
      serial[i]->flush();
      t1 = millis();
      // trigger reading
      digitalWrite(trig[i], HIGH);

      // while there is data coming in, read it
      while(1) {
        if(serial[i]->available() > 0) {
          // shift rx buffer
          for(j = 0; j < 4; j++) {
            rxbuf[j] = rxbuf[j + 1];
          }
          rxbuf[4] = serial[i]->read() & 0x00ff;
          if(rxbuf[4] == '\r') {
            break;
          }
        }
        if(millis() > t1 + 100) {
          // timeout - set to distance of "999"
          rxbuf[1] = '9';
          rxbuf[2] = '9';
          rxbuf[3] = '9';
          rxbuf[4] = '\r';
          break;
        }
      }
      // ok, got a message, stop trigger
      digitalWrite(trig[i], LOW);
      // substitute port letter for 'R'
      rxbuf[0] = letters[i];    
      // determine if this is the last reading
      max_sensor = 0;
      for(j = 0; j < 4; j++) {
        if(enable[j]) {
          max_sensor = j;
        }
      }
      // if not last reading, substitute tab instead of CR
      if(i != max_sensor) {
        rxbuf[4] = '\t';
      }
      rxbuf[5] = 0;
      Serial.print(rxbuf);
      // turn off indicator led
      digitalWrite(leds[i], LOW);
    }
  }
}

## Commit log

2018-01-13 Change directory structure Add Sonar class for robot
2018-01-27 Added pcb Folder Changed file structure to make Arduino happy Changed parser to support simultaneous operation
2018-01-27 Actually added pcb folder
2018-01-27 Working on FeatherM0 schematic symbol
    [Ultrasonic_mux.kicad_pcb, Ultrasonic_mux.sch]
2018-01-29 finished schematic for pcb
2018-01-30 Creating schematic.
2018-01-31 Finished RX ports and finished 3-pin connectors and power.
    [Ultrasonic_mux.sch]
2018-02-01 Getting rid of ports 7 and 8, starting to label indicators/triggers.
    [Ultrasonic_mux.sch]
2018-02-01 Finished labeling indicators/triggers and organized layout.
    [Ultrasonic_mux.sch]
2018-02-02 Changed voltage
    [Ultrasonic_mux.sch]
2018-02-03 Finished schematic
    [Ultrasonic_mux.sch]
2018-02-03 Added netlist restarted footprint associations for board
    [Ultrasonic_mux.sch]
2018-02-03 Finished footprints, starting layout of board.
    [Ultrasonic_mux.sch]
2018-02-03 Organized layout.
    [Ultrasonic_mux.kicad_pcb]
2018-02-03 Hopefully finished track routes.
    [Ultrasonic_mux.kicad_pcb, Ultrasonic_mux.sch]
2018-02-05 BD: Reduced board size to 150x100mm for easier fit on 'bot, and reduced mechanical stress. Added vias to permit easier mods (runner cuts and soldered wire reconnect to another pad/circuit)
    It still thinks 5v is not connected!
    Tried replacing connecting segments to J13 and U1
    Tried adding another trace to each on bottom of board
    [Ultrasonic_mux.kicad_pcb]
2018-02-05 Added logo and text Still an issue with the 5v connection Order is based on gerber's, so shouldn't be a problem Worst case, small jumper wire Created gerber files
    [Ultrasonic_mux.kicad_pcb]
2018-02-05 Now with the gerber files
    [Ultrasonic_mux-B.Cu.gbl, Ultrasonic_mux-B.Mask.gbs, Ultrasonic_mux-B.SilkS.gbo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]
2018-02-08 Checked layout, doesn't look like anything is wrong.
    [Ultrasonic_mux.kicad_pcb]
2018-02-17 Add SAMD21_serial.ino test routine All 6 serial ports working
    Unknown change to the pcb project
    Added some data sheets
2018-02-17 All 6 sensors operating in parallel Output string format is as in the former mux
